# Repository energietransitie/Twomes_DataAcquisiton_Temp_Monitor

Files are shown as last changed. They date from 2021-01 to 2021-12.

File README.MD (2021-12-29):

# Twomes Boiler Monitor Module Firmware
Firmware for the Twomes Boiler Monitor Module. 

## Table of contents
* [General info](#general-info)
* [Deploying](#deploying)
* [Developing](#developing) 
* [Features](#features)
* [Pairing](#pairing)
* [Status](#status)
* [License](#license)
* [Credits](#credits)

## General info
This firmware is designed to run on the ESP32 of the [Twomes Temperature Monitor hardware](https://github.com/energietransitie/twomes-temp-monitor-hardware), in combination with two [DS18b20(Z)](https://www.maximintegrated.com/en/products/sensors/DS18B20.html) temperature sensors in clamps that can be connected the supply water piple (from the boiler to the hydronic radiators) and return water pipes returning from the hydronic radiators to the boiler. We do not expect the end user of the device to be able to distinguish between supply and return water pipes and leave the determination of supply and return to the analysis phase of the data.

The ESP32 reads the temperatures from both sensors and stores them in [RTC fast memory](https://docs.espressif.com/projects/esp-idf/en/latest/esp32/api-guides/memory-types.html#rtc-fast-memory), to preserve them during the deep sleep interval between brief moments when the ESP32 needs to be awake for data acquisition. After a series of 20 measurements at fixed time intervals, the ESP32 will send the series of measurements to the [Twomes P1 Gateway measurement device](https://github.com/energietransitie/twomes-p1-gateway-firmware) using the ESP-NOW protocol.

Via the [Twomes P1 Gateway measurement device](https://github.com/energietransitie/twomes-p1-gateway-firmware), the Twomes Boiler Monitor Module sends the following properties to the Twomes server:
| Sensor  | Property | Unit | [Printf format](https://en.wikipedia.org/wiki/Printf_format_string) | Measurement interval \[h:mm:ss\] | Description |
|---|---|---|---|---|---|
| DS18b20 | `boilerTemp1` | °C | %.1f | 0:00:10 | temperature of hydronic supply/return pipe |
| DS18b20 | `boilerTemp2` | °C | %.1f | 0:00:10 | temperature of hydronic supply/return pipe |

## Pairing
After [deploying](#deploying) and installation in the home, the Twomes Boiler Monitor Module should be [paired as a satellite to the Twomes P1 Gateway measurement device](https://github.com/energietransitie/twomes-p1-gateway-firmware/blob/main/README.md#pairing-satellites).

## Deploying
This section describes how you can deploy binary releases of the firmware, i.e. without changing the source code, without a development environment and without needing to compile the source code.

### Prerequisites
To deploy the firmware, in addition to the [generic prerequisites for deploying Twomes firmware](https://github.com/energietransitie/twomes-generic-esp-firmware#prerequisites), you need:
* a 3.3V TTL-USB Serial Port Adapter (e.g. [FT232RL](https://www.tinytronics.nl/shop/en/communication-and-signals/usb/ft232rl-3.3v-5v-ttl-usb-serial-port-adapter), CP210x, etc..), including the cable to connect ths adapter to a free USB port on your computer (a USB to miniUSB cable in the case of a [FT232RL](https://www.tinytronics.nl/shop/en/communication-and-signals/usb/ft232rl-3.3v-5v-ttl-usb-serial-port-adapter));
* You need to place a 3.6V Lithium AA-battery (e.g. SAFT LS14500) in its holder to power the board, as the Twomes Boiler Monitor Module is not powered via the 6 pin programming connector.
* Find a row of 6 holes holes (J1 in the corner of the PCB of the Boiler Monitor Module), find the `GND` pin (see  top of the PCB), align the 6 pins of the serial port adapter such that `GND` and other pins match; then connect the serial port adapter to your computer and connect the 6 pins of the serial port adapter to the 6 holes on the PCB.

### Uploading firmware
* Download the [binary release for your device](https://github.com/energietransitie/twomes-boiler-monitor-firmware/releases) and extract it to a directory of your choice.
* Follow the [generic Twomes firmware upload instructions ](https://github.com/energietransitie/twomes-generic-esp-firmware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), with the exceptions mentioned below:
	* When you see the beginning of the sequence `Connecting ......_____......`, press and hold the button labeled `GPIO0 (SW2)` on the PCB, then briefly press the button labeled `RESET (SW1)`. 
	* You should see an indication that the firmware is being written to the device.
 	* When the upload is finished, view the serial output with a serial monitor tool like [PuTTY](https://www.chiark.greenend.org.uk/~sgtatham/putty/) or the utility of your IDE (115200 baud). Press `RESET (SW1)` shortly to  make sure the firmware boots. 
	* Remove the battery or insert a battery insulating pull tab when you do not plan to use the boiler monitor module immediately, to prevent unnecessary battery drain. In particular, when the temperature sensors are not connected, power consumption is higher. 

## Developing 
This section describes how you can change the source code using a development environment and compile the source code into a binary release of the firmware that can be depoyed, either via the development environment, or via the method described in the section [Deploying](#deploying).

Please see the [generic Twomes firmware developing instructions](https://github.com/energietransitie/twomes-generic-esp-firmware#developing), with the exceptions mentioned below:
* When you see the beginning of the sequence `Connecting ......_____......`, press and hold the button labeled `GPIO0 (SW2)` on the PCB, then briefly press the button labeled `RESET (SW1)`. 
* You should see an indication that the firmware is being written to the device.

## Features
List of features ready and TODOs for future development. 

Ready:
* Pairing with a [Twomes P1 Gateway measurement device](https://github.com/energietransitie/twomes-p1-gateway-firmware)
* Measure temperatures using two DS18b20 sensors
* Deep sleep between data acquisition for ultra-low power consumption
* Send measurement data to [Twomes P1 Gateway measurement device](https://github.com/energietransitie/twomes-p1-gateway-firmware) using ESP-NOW

To-do:
* Align indication of status and error via LEDs with other measurement devices.

## Status
Project is: in Progress.

## License
This software is available under the [Apache 2.0 license](./LICENSE.md), Copyright 2021 [Research group Energy Transition, Windesheim University of Applied Sciences](https://windesheim.nl/energietransitie) 

## Credits
This software is a collaborative effort of:
* Sjors Smit ·  [@Shorts1999](https://github.com/Shorts1999)
* Fredrik-Otto Lautenbag ·  [@Fredrik1997](https://github.com/Fredrik1997)
* Gerwin Buma ·  [@GerwinBuma](https://github.com/GerwinBuma) 
* Werner Heetebrij ·  [@Werner-Heetebrij](https://github.com/Werner-Heetebrij)
* Henri ter Hofte · [@henriterhofte](https://github.com/henriterhofte) · Twitter [@HeNRGi](https://twitter.com/HeNRGi)

Product owner:
* Marco Winkelman · [@MarcoW71](https://github.com/MarcoW71)

We use and gratefully acknowlegde the efforts of the makers of the following source code and libraries:

* [Arduino core for the ESP32](https://github.com/espressif/arduino-esp32), by Espressif, licensed under [GNU LGPL-2.1](https://github.com/espressif/arduino-esp32/blob/master/LICENSE.md)
* [Library for Dallas/Maxim 1-Wire Chips](https://github.com/PaulStoffregen/OneWire), by Paul Stoffregen and others, licensed under [various licernses](https://github.com/PaulStoffregen/OneWire)
* [Arduino Library for Maxim Temperature Integrated Circuits](https://github.com/milesburton/Arduino-Temperature-Control-Library), by Miles Burton, licensed under [GNU LGPL-2.1](https://github.com/milesburton/Arduino-Temperature-Control-Library#license)

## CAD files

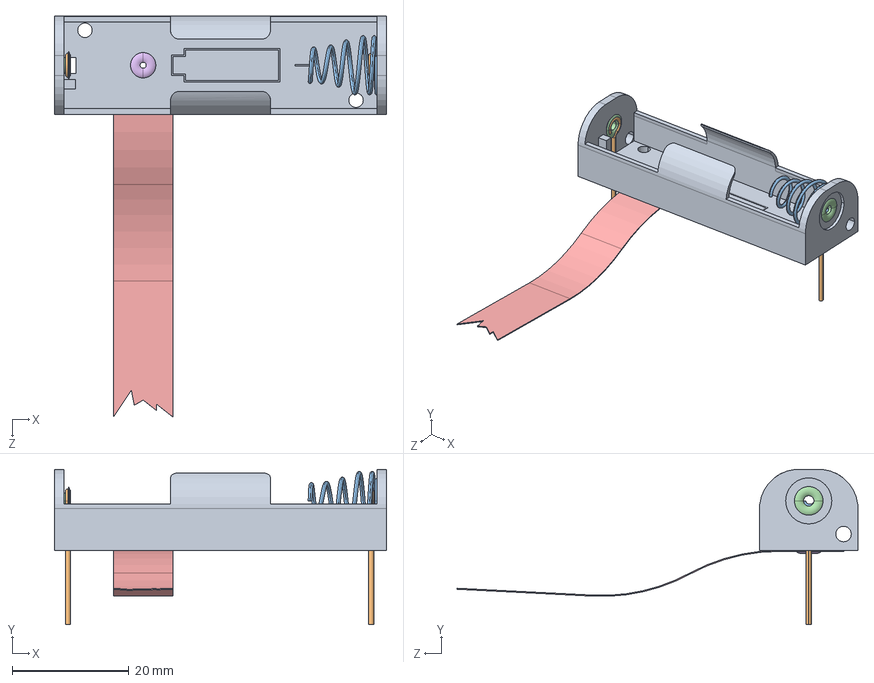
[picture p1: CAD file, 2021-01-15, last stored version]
hardware_design/models/keystone-PN2460RB.SLDASM
57.0 x 26.6 x 68.8 mm
2460-1RB.STEP
2464-2.STEP x 2
2464-spring1.STEP
2460-2_for assemly.STEP x 2
Ribon-Red.STEP
2464-for ribon.STEP

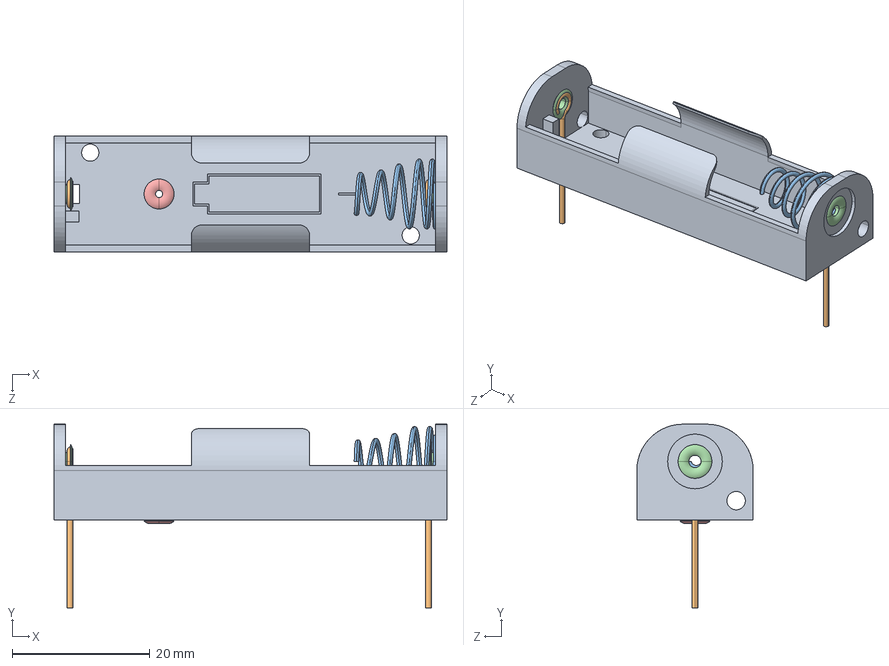
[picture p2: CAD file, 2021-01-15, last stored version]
hardware_design/models/keystone-PN2460_without_ribbon.STEP
57.0 x 26.6 x 16.9 mm
2460-1RB.STEP
2464-2.STEP x 2
2464-spring1.STEP
2460-2_for assemly.STEP x 2
2464-for ribon.STEP

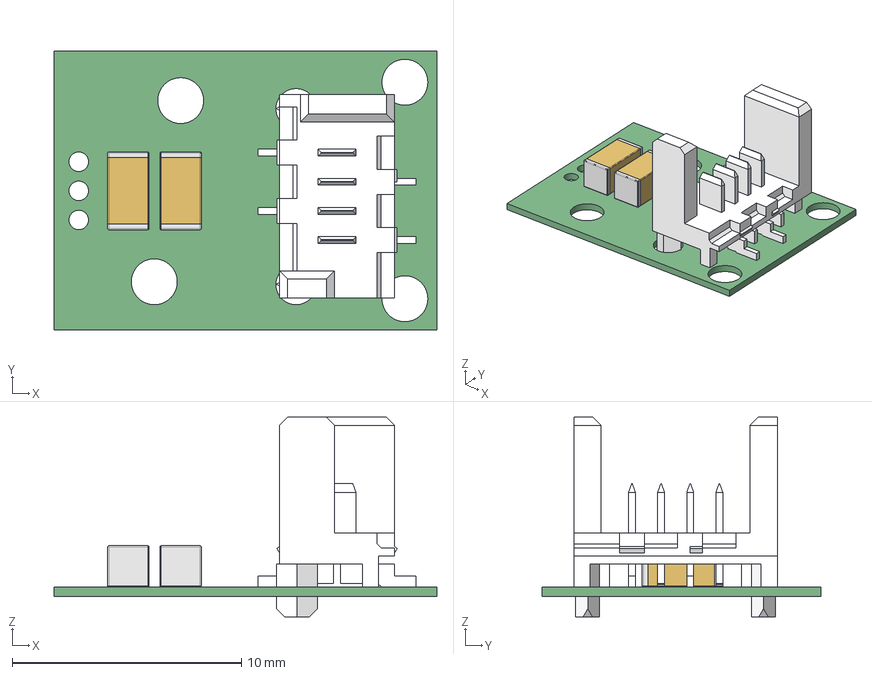
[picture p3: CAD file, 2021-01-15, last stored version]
hardware_design/Twomes_Monitor_slave.step
16.7 x 12.2 x 8.70 mm

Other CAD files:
hardware_design/Open_CASCADE_STEP_translator_6.8_1.3.1.x_t.SLDPRT
hardware_design/models/keystone-PN2460_without_ribbon.SLDASM

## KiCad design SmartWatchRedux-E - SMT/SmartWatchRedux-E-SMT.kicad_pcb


Board: 2 copper layers, 24.7 x 69.9 mm, 6 parts (0 on the bottom side), 33 nets.

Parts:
BAT1: CR2032; BatteryHolder_Keystone_1060_1x2032
C1: 0.1uF; C_1206_3216Metric
CN1: 27C256Socket; DIP-28_W15.24mm
U1: ROM; DIP-28_W15.24mm_Socket
U2: DS1315; DIP-16_W7.62mm
Y1: 32.768 KHz; Crystal_SMD_3215-2Pin_3.2x1.5mm

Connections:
/XTAL1: U2.1, Y1.1
/XTAL2: U2.2, Y1.2
GND: BAT1.2, C1.2, CN1.14, U1.14, U2.5, U2.8, U2.14
unnamed: BAT1.1, U2.4
unnamed: CN1.1, U1.1, U2.13
unnamed: CN1.2, U1.2
unnamed: CN1.3, U1.3
unnamed: CN1.4, U1.4
unnamed: CN1.5, U1.5
unnamed: CN1.6, U1.6
unnamed: CN1.7, U1.7
unnamed: CN1.8, U1.8, U2.3
unnamed: CN1.9, U1.9
unnamed: CN1.10, U1.10, U2.6
unnamed: CN1.11, U1.11, U2.7
unnamed: CN1.12, U1.12
unnamed: CN1.13, U1.13
unnamed: CN1.15, U1.15
unnamed: CN1.16, U1.16
unnamed: CN1.17, U1.17
unnamed: CN1.18, U1.18
unnamed: CN1.19, U1.19
unnamed: CN1.20, U2.11
unnamed: CN1.21, U1.21
unnamed: CN1.22, U1.22, U2.12
unnamed: CN1.23, U1.23
unnamed: CN1.24, U1.24
unnamed: CN1.25, U1.25
unnamed: CN1.26, U1.26
unnamed: CN1.27, U1.27
unnamed: U1.20, U2.10
unnamed: U2.9, U2.15
VCC: C1.1, CN1.28, U1.28, U2.16

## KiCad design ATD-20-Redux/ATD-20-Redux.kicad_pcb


Board: 2 copper layers, 24.3 x 64.1 mm, 5 parts (0 on the bottom side), 9 nets.

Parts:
BAT1: CR2032; BatteryHolder_Keystone_1060_1x2032
C1: 0.1uF; C_Disc_D4.3mm_W1.9mm_P5.00mm
J1: RTC Pins; DIP-28_W15.24mm_Socket
U1: DS1315; DIP-16_W7.62mm
Y1: 32.768 KHz; Crystal_C38-LF_D3.0mm_L8.0mm_Horizontal

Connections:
/D0: J1.11, U1.6, U1.7
/XTAL1: U1.1, Y1.1
/XTAL2: U1.2, Y1.2
/~CS_RTC: J1.20, U1.11
/~IOR: J1.22, U1.12
/~IOW: J1.27, U1.3
GND: BAT1.2, C1.2, J1.14, U1.5, U1.8, U1.9, U1.14
unnamed: BAT1.1, U1.4
VCC: C1.1, J1.28, U1.13, U1.16

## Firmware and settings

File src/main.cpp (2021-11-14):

#include <Arduino.h>
#include <OneWire.h>           //for DS18B20 support
#include <DallasTemperature.h> //for DS18B20 support
#include <WiFi.h>               //For setting WiFi mode REVIEW could this be done using the esp_wifi.h as well?
#include <esp_now.h>            //For sending and receiving ESP-NOW messages
#include <espnow_settings.h>    //Contains addresses and message limits
#include <esp_wifi.h>           //For setting channel
#include <nvs.h>                //For storing and reading Gateway MAC and channel
#include <rom/rtc.h>            //Get wakeup reason

//Roomsensor libraries are made in C:
//Should the extern "C" be moved to inside the libraries?
#ifdef __cplusplus
extern "C" {
#endif
#include <sensor_IO.h>
#include <twomes_sensor_pairing.h>
#ifdef __cplusplus
}
#endif

//DEBUG DEFINES:
#define DEBUG 1              //Global debug define enable

#define DEBUG_BOOT 1            //Debug startup (Able to boot, check for temp-sensors, CPU frequency)
#define DEBUG_TEMPERATURE 1     //Debug Temperature measurements (Print temperature values)
#define DEBUG_TIME 1            //Debug the time adjustment value (Print time since last boot in us)
#define DEBUG_ESPNOW_SEND 1     //Debug for when sending ESP-Now messages (Print payload and destination MAC address)
#define DEBUG_CALLBACK 1        //Debug for ESP-Now callback function (de-initalising and check for ACK)
#define DEBUG_ERRORS 1          //Debug error-messages (init-failures)
#define DEBUG_PROVISIONING 1    //Debug sensor provisioning

/** -------------------------------------------------/
 * @todo:
 * - Test sensor readings [V]
 * - set configurable settings using GPIO or Provisioning through Gateway []
 * - Change temp reading in float to temp reading in uint16_t [V]
 * - Put Debug/Serial operation in #if to disable for real tests [V]
 * - Improve code readability []
 * - implement support for roomTemp version (si7051 sensor) [] //REVIEW should this be entirely seperate code?
 * - automate deep- or light sleep depending on interval time [] (light sleep for <=10 seconds, deep sleep for >10 seconds)
----------------------------------------------------*/

#define ONEWIRE_BUS_PIN 25  //pin for OneWire bus
#define SUPERCAP_ENABLE 27  //Pull low to enable supercap

#define uS_TO_S_FACTOR 1000000ULL                    /* Conversion factor for micro seconds to seconds */
#define mS_TO_S_FACTOR 1000ULL                       /* Conversion factor for milli seconds to seconds */
#define TIME_TO_SLEEP 10                             /* Time between measurements */
#define INTERVAL_US (TIME_TO_SLEEP * uS_TO_S_FACTOR) /* desired interval between measurements in us */
#define TIME_TO_CONVERSION 750                       /* Time ESP32 will go to sleep for conversion(in milliseconds) */
#define RETRY_INTERVAL 5                             /* Amount of measurements before a new ESP-Now attempt after a Fail To Send */

#define PAIRING_TIMEOUT_uS 20*uS_TO_S_FACTOR         /* timeout for pairing mode*/

#define MAX_SAMPLES_MEMORY 60    //maximum memory allocated for samples, derived from maximum amount of samples that fit into a single message
#define ESPNOW_SEND_MINIMUM 20       //Minimum amount of measurements taken before ESP-Now transmissions are started

#if (MAX_SAMPLES_MEMORY != MAX_SAMPLES_ESPNOW)
#error This is not supported yet
#endif

//systemStates
enum systemStates {
    UNKNOWN,           //boot after power loss (RTC data cleared) or first boot
    INIT_MEASUREMENT,  //state where measurement is initialised
    READ_MEASUREMENT,   //state where measurement is read
    PROVISION_SENSOR    //State where sensor gets provisioned with channel and gateway MAC through ESP-Now
}; /* systemstates*/
RTC_DATA_ATTR systemStates systemState = UNKNOWN;           //variable in RTC memory where current system state is saved

RTC_DATA_ATTR uint8_t currentMeasurement = 0;       //variable in RTC memory where number of current measurement is stored
RTC_DATA_ATTR uint64_t previousTime = 0;            //REVIEW
RTC_DATA_ATTR uint64_t time_correction = 200000;    //REVIEW, initial time correction
RTC_DATA_ATTR uint16_t burstNumber = 0;             //Store the amount of databursts that have been done with ESP-Now, for syncing with gateway

//Register peer
esp_now_peer_info_t peerInfo; //place to save ESPNOW peer info

//prototype functions
void sendESPNOWmessage(); //function to send ESPNOW message
void onDataSent(const uint8_t *macAddress, esp_now_send_status_t status); //ESP-Now send callback function
void onDataReceive(const uint8_t *macAddress, const uint8_t *payload, int length); //ESP-Now receive callabck function

OneWire oneWireBus(ONEWIRE_BUS_PIN); //software OneWire bus

DallasTemperature tempSensors(&oneWireBus); //temperature object


RTC_DATA_ATTR int16_t temp1[MAX_SAMPLES_MEMORY];
RTC_DATA_ATTR int16_t temp2[MAX_SAMPLES_MEMORY];
RTC_DATA_ATTR bool waitForCallback = false;

//Twomes Measurement type enum:
enum ESPNOWdataTypes {
    BOILERTEMP,
    ROOMTEMP,
    CO2,
};

//NEW int16_t version to increase amount of measurements in single burst
typedef struct ESP_message {
    uint8_t measurementType = BOILERTEMP;  //Type of measurements
    uint8_t numberofMeasurements;                       //number of measurements in burst
    uint16_t index;                                     //Number identifying the message, only increments on receiving an ACK from Gateway. Could be uint8_t since overflows are ignored?
    uint16_t intervalTime = TIME_TO_SLEEP;               //Interval between measurements, for timestamping in gateway
    int16_t pipeTemps1[MAX_SAMPLES_ESPNOW];             //measurements of the first temperature sensor
    int16_t pipeTemps2[MAX_SAMPLES_ESPNOW];             //measurements of the second temperature sensor
} ESP_message;
ESP_message prepareMessage; //allocate space for this struct //Should/can this be done dynamically?

void setup() {
#if defined(DEBUG) //Serial only has to be started when debugging:
    Serial.begin(115200);
#endif
    pinMode(BUTTON_GPIO0_SW2, INPUT_PULLUP);
    pinMode(BUTTON_GPIO15_SW3, INPUT_PULLUP);
    pinMode(GREEN_LED_STATUS_D2, OUTPUT);
    pinMode(RED_LED_ERROR_D1, OUTPUT);
    pinMode(SUPERCAP_ENABLE, OUTPUT);
    digitalWrite(SUPERCAP_ENABLE, HIGH); //Pmos = active low

    //Get the wakeup reason:
    RESET_REASON reset_reason = rtc_get_reset_reason(PRO_CPU_NUM);
    if (reset_reason == RTCWDT_BROWN_OUT_RESET) {
        delay(10000);
        reset_reason = POWERON_RESET;
    }
    //Check for BUTTON_GPIO15_SW3 pressed on boot
    if (reset_reason == POWERON_RESET) {
        systemState = systemStates::PROVISION_SENSOR;
    } //if(!digitalRead(BUTTON_GPIO15_SW3))

    //Needs loop for lightsleep, since program counter is saved
    while (1) {
        //this is a state machine
        switch (systemState) {
            //First boot or power loss, re-initialise:
            case systemStates::UNKNOWN: //first run/sensors not connected?, this could be detection for hardware variant
#if defined(DEBUG) & defined(DEBUG_BOOT)
//Blink LED to indicate being in state "UNKNOWN"
                digitalWrite(RED_LED_ERROR_D1, HIGH);
                delay(50);
                digitalWrite(RED_LED_ERROR_D1, LOW);
                delay(50);
                digitalWrite(RED_LED_ERROR_D1, HIGH);
                delay(50);
                digitalWrite(RED_LED_ERROR_D1, LOW);
                Serial.println("Device has started");
                Serial.println("booted for the first time");
#endif
                tempSensors.begin();
                delay(50); //give time for initing
                //Check that both sensors are connected:
                if (tempSensors.getDeviceCount() != 2) {
#if defined(DEBUG) & defined(DEBUG_BOOT)
                    Serial.println("Missing temperature sensors!");
                    Serial.println(tempSensors.getDeviceCount());
#endif
                    delay(500);
                } //if getDeviceCount != 2
                else {
#if defined(DEBUG) & defined(DEBUG_BOOT)
                    Serial.println("Ready to start measuring!");
#endif
                    systemState = systemStates::INIT_MEASUREMENT;
                } //if get DeviceCount == 2
                break; //systemStates::UNKNOWN
            //init measurement
            case systemStates::INIT_MEASUREMENT:
                tempSensors.begin();                     //initialize sensor
                tempSensors.setWaitForConversion(false); //disable the wait for conversion
                tempSensors.requestTemperatures();       //start conversion
                esp_sleep_enable_timer_wakeup(TIME_TO_CONVERSION * mS_TO_S_FACTOR); //sleep for 750 ms during conversion

                systemState = systemStates::READ_MEASUREMENT; //set conversion is started bit

                esp_light_sleep_start(); //go to sleep

                break; //end of systemStates::INIT_MEASUREMENT
            case systemStates::READ_MEASUREMENT: //read measurements
            {
#if defined(DEBUG) & defined(DEBUG_BOOT)
                Serial.println("Device has started");
#endif
                //Theoretically speaking, currentMeasurement should in this case always be equal to MAX_SAMPLES_MEMORY, and never exceed it.
                if (currentMeasurement >= MAX_SAMPLES_MEMORY) {
                    //move all samples "RETRY_INTERVAL" amount of spaces in memory, overwriting "RETRY_INTERVAL" amount of old measurements and making room for "RETRY_INTERVAL" amount new ones.
                    memmove(temp1, &temp1[(currentMeasurement - MAX_SAMPLES_MEMORY) + RETRY_INTERVAL], (MAX_SAMPLES_MEMORY - RETRY_INTERVAL) * sizeof(temp1[0]));
                    memmove(temp2, &temp2[(currentMeasurement - MAX_SAMPLES_MEMORY) + RETRY_INTERVAL], (MAX_SAMPLES_MEMORY - RETRY_INTERVAL) * sizeof(temp2[0]));
                    currentMeasurement = MAX_SAMPLES_MEMORY - RETRY_INTERVAL;
                }//if(currentMeasurement >= MAX_SAMPLES_MEMORY)

                DeviceAddress address1;
                DeviceAddress address2;
                tempSensors.getAddress(address1, 0);
                tempSensors.getAddress(address2, 1); //Using same bus
                temp1[currentMeasurement] = tempSensors.getTemp(address1);
                temp2[currentMeasurement] = tempSensors.getTemp(address2); //Using same bus
#if defined(DEBUG) & defined(DEBUG_TEMPERATURE)
                Serial.print("Temp1: ");
                Serial.println(temp1[currentMeasurement], HEX);
                Serial.print("Temp2: ");
                Serial.println(temp2[currentMeasurement], HEX);
                Serial.print("Celsius values: ");
                Serial.print("Temp 1: ");
                Serial.print(temp1[currentMeasurement] * 0.0078125f); //Conversion to Celsius from DallasTemperature library to check if HEX value was read correctly
                Serial.print("Temp 2: ");
                Serial.println(temp2[currentMeasurement] * 0.0078125f); //Conversion to Celsius from DallasTemperature library to check if HEX value was read correctly
#endif
                if ((temp1[currentMeasurement] == DEVICE_DISCONNECTED_RAW) || (temp2[currentMeasurement] == DEVICE_DISCONNECTED_RAW)) {
#if defined(DEBUG) & defined(DEBUG_TEMPERATURE)
                    Serial.println("\n\n\n\nNow everything should be deleted, and starting again"); //temp error message
#endif
                    currentMeasurement = 0;            //set to zero to reinit all.
                    systemState = systemStates::UNKNOWN; //go back to previous step
                    break;                             // init everything again
                }//if(temp1 || temp2)
                currentMeasurement++; //Add to currentMeasurement AFTER measuring, but BEFORE sending! (0 indexing for writing to memory, but not for comparing to ready_to_send)
#if defined(DEBUG) & defined(DEBUG_TEMPERATURE)
                Serial.printf("\n\n\ncurrentMeasurement: %u\n", currentMeasurement);
#endif
                struct timeval tv;
                gettimeofday(&tv, NULL);
                int64_t time_us = (int64_t)tv.tv_sec * 1000000L + (int64_t)tv.tv_usec; //code needed to get the time in microseconds
                int32_t time_delta = time_us - previousTime;                          //calculate the time that is elapsed since the last measurement
                previousTime = time_us;                                               // write current time to memory for next cycle
#if defined(DEBUG) & defined(DEBUG_TIME)
                Serial.println(time_delta);
#endif
                time_correction += (time_delta - INTERVAL_US);                                   // finetune time correction
                esp_sleep_enable_timer_wakeup(TIME_TO_SLEEP * uS_TO_S_FACTOR - time_correction); //sleep until next temperature reading
                //if there are not enough samples yet
                if (currentMeasurement < ESPNOW_SEND_MINIMUM) {
#if defined(DEBUG) & defined(DEBUG_TEMPERATURE)
                    Serial.printf("Collecting new measurement\n");
#endif
                } //if(currentMEasurement<ESPNOW_SEND_MINIMUM)
                else if (currentMeasurement == ESPNOW_SEND_MINIMUM || (currentMeasurement > ESPNOW_SEND_MINIMUM && !((currentMeasurement - ESPNOW_SEND_MINIMUM) % RETRY_INTERVAL))) { //if there are enough samples to send
                    sendESPNOWmessage();
                    waitForCallback = true;
                    while (waitForCallback) {
#if defined(DEBUG) && defined(DEBUG_CALLBACK)
                        Serial.println("waiting for callback");
#endif
                        delay(500);
                    } //Wait for ESP-Now Callback function
                }//esle if (enough samples to send)

                systemState = systemStates::INIT_MEASUREMENT;
#ifdef DEBUG
                Serial.println("Entering Sleep mode");
#endif
#if (TIME_TO_SLEEP>5)  //at a delay of more than 10 
                esp_deep_sleep_start();
#else
                esp_light_sleep_start(); //go to sleep
#endif
            }//case READ_MEASUREMENT
            break;

            case systemStates::PROVISION_SENSOR:
            {
                Serial.println("In pairing mode");
                digitalWrite(SUPERCAP_ENABLE, LOW); //Enable supercap
                WiFi.mode(WIFI_STA); //Enter STA mode to enable ESP-Now
                if (esp_now_init() != ESP_OK) { //if initing wasn't succesful
#if defined(DEBUG) & defined(DEBUG_ERRORS)
                    Serial.println("Error initializing ESP-NOW");
#endif
                    esp_now_deinit();
                    WiFi.mode(WIFI_OFF);
                    break;
                }
                //Set the channel to the defined channel for Sensor pairing (Should be the same in the P1-Gateway!!)
                esp_wifi_set_channel(ESPNOW_PAIRING_CHANNEL, WIFI_SECOND_CHAN_NONE);

                esp_now_register_recv_cb(onDataReceive);
                int64_t startTime = esp_timer_get_time();
                //Set 20 second timeout on pairing:
                while ((startTime + PAIRING_TIMEOUT_uS > esp_timer_get_time())) {
                    digitalWrite(GREEN_LED_STATUS_D2, HIGH);
                    vTaskDelay(500);
                    digitalWrite(GREEN_LED_STATUS_D2, LOW);
                    vTaskDelay(500);
                }
                esp_now_unregister_recv_cb();
                esp_now_deinit();
                WiFi.mode(WIFI_OFF);
                digitalWrite(SUPERCAP_ENABLE, HIGH); //Close supercap
                //Indicate pair fail:
                gpio_set_level((gpio_num_t)RED_LED_ERROR_D1, 1);
                delay(5000);
                systemState = systemStates::UNKNOWN;
            }//case PROVISION_SENSOR
            break;
            default:
            {
            }//default
            break;
        }// switch systemState
    } //while(1)
}

void sendESPNOWmessage() {
    //Enable SuperCap to assist with power:
    digitalWrite(SUPERCAP_ENABLE, LOW);

    //Get the MAC address and channel from NVS:
    uint8_t macAddress[6];
    uint8_t channel;
    esp_err_t err = getGatewayData(macAddress, sizeof(macAddress), &channel);
    if (err != ESP_OK) {
        ESP_LOGE("READ-CHANNEL", "Error trying to read data from NVS: %s", esp_err_to_name(err));
    }

    //Enable Wi-Fi in station mode, to allow ESP-Now
    WiFi.mode(WIFI_STA);

    if (esp_now_init() != ESP_OK) { //if initing wasn't succesful, exit
#if defined(DEBUG) & defined(DEBUG_ERRORS)
        Serial.println("Error initializing ESP-NOW");
#endif
        esp_now_deinit();
        WiFi.mode(WIFI_OFF);
        return;
    }

    esp_now_register_send_cb(onDataSent); //register callback to fetch send reaction

#if defined(DEBUG)
//print the read channel and MAC address
    Serial.print(" Now validating NVS address: ");
    for (uint8_t i = 0; i < 6;i++) {
        Serial.print(macAddress[i], HEX);
        Serial.print(':');
    }
    Serial.printf("Sending on channel %u", channel);
#endif
    // Add peer
    memcpy(peerInfo.peer_addr, macAddress, 6);
    //Before sending, retrieve the Wi-Fi channel of the local network:
    esp_wifi_set_channel(channel, WIFI_SECOND_CHAN_NONE);

    if (esp_now_add_peer(&peerInfo) != ESP_OK) //add to peer
    {
#if defined(DEBUG) & defined(DEBUG_ERRORS)
        Serial.println("Failed to add peer");
#endif
        esp_now_deinit();
        WiFi.mode(WIFI_OFF);
        //esp_now_del_peer(&peerInfo.peer_addr);
        return;
    }


    prepareMessage.numberofMeasurements = currentMeasurement;
    prepareMessage.index = burstNumber;
    //Copy the temperature data into the struct
    memcpy(prepareMessage.pipeTemps1, temp1, MAX_SAMPLES_MEMORY * sizeof(temp1[0]));
    memcpy(prepareMessage.pipeTemps2, temp2, MAX_SAMPLES_MEMORY * sizeof(temp2[0]));
#if defined(DEBUG_ESPNOW_SEND) & defined(DEBUG)
    // Serial.printf("[ESPNOW]: prepareMessage.numberofMeasurements = %u\n", prepareMessage.numberofMeasurements);
    // Serial.printf("[ESPNOW]: prepareMessage.intervalTime = %u\n", prepareMessage.intervalTime);
    // Serial.printf("[ESPNOW]: preparemessage.index = %u\n", prepareMessage.index);
    // for (uint8_t counter1 = 0; counter1 < prepareMessage.numberofMeasurements; counter1++) {
    //     // printf("[ESPNOW]: prepareMessage.pipeTemps1[%u] = %f\n", counter1, prepareMessage.pipeTemps1[counter1]); //Old float version
    //     // printf("[ESPNOW]: prepareMessage.pipeTemps2[%u] = %f\n", counter1, prepareMessage.pipeTemps2[counter1]);
    //     Serial.printf("[ESPNOW]: prepareMessage.pipeTemps1[%u] = %f\n", counter1, prepareMessage.pipeTemps1[counter1] * 0.0078125f); //New int16_t, print as float for debugging
    //     Serial.printf("[ESPNOW]: prepareMessage.pipeTemps2[%u] = %f\n", counter1, prepareMessage.pipeTemps2[counter1] * 0.0078125f);
    // }
    // Serial.printf("[ESPNOW]: This should be the message\n");
#endif

    //Send the data through ESP-Now
    esp_err_t result = esp_now_send(macAddress, (uint8_t *)&prepareMessage, sizeof(prepareMessage));

    //Check that the message was correctly transmitted 
    if (result != ESP_OK) {
#if defined(DEBUG) & defined(DEBUG_ESPNOW_SEND)
        Serial.printf("Error sending the data, with return %u\n", result);
#endif
        esp_now_deinit();
        WiFi.mode(WIFI_OFF);
        return;
    }
#if defined(DEBUG) & defined(DEBUG_ESPNOW_SEND)
    else {
        Serial.print("[ESPNOW]: Sent with success to address: ");
        for (uint8_t i = 0; i < 6; i++) {
            Serial.print((peerInfo.peer_addr[i]), HEX);
            Serial.print(":");
        }
        Serial.println();
    }
#else
    else
        return;
#endif
}

//callback on ESP message sent, use status to check for ACK
void onDataSent(const uint8_t *macAddress, esp_now_send_status_t status) {
#if defined(DEBUG) & defined(DEBUG_CALLBACK)
    Serial.printf("[ESPNOW]: unregister cb: %d\n", esp_now_unregister_send_cb());
    // Serial.printf("[ESPNOW]: delete peer: %d\n", esp_now_del_peer(gatewayAddress));
    Serial.println(String("[ESP-Now] De-init ") + String((esp_now_deinit() ? "failed" : "Succes")));
    Serial.println(String("[WiFi] Turn off WiFi ") + String(WiFi.mode(WIFI_OFF) ? "Succes" : "Failed"));
#else
    esp_now_unregister_send_cb();
    esp_now_del_peer(gatewayAddress);
    esp_now_deinit();
    WiFi.mode(WIFI_OFF);
#endif
    digitalWrite(SUPERCAP_ENABLE, HIGH); //Disable supercap
#if defined(DEBUG) & defined(DEBUG_CALLBACK)
    Serial.print("\r\nLast Packet Send Status: ");
#endif
    if (status == ESP_NOW_SEND_SUCCESS) {
#if defined(DEBUG) & defined(DEBUG_CALLBACK)
        Serial.printf("Delivery Success, so currentMeasurement =0\n");
#endif
        currentMeasurement = 0; //zero this if measurement succeed
        burstNumber++;          //Add to the total amount of samples sent
    }
#if defined(DEBUG) & defined(DEBUG_CALLBACK)
    else {
        Serial.printf("Delivery Fail\n");
    }
#endif
    //Go to sleep only after ESP_Now message is completely processed

    waitForCallback = false;
    return;
}



void loop() {}

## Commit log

2020-11-11 change foldername due false characters
    [Twomes_Monitor.PrjPCB, main.SchDoc]
2020-12-02 working on schematic
    [Twomes_Monitor.PrjPCB, Twomes_Monitor.SCHLIB, main.SchDoc]
2020-12-03 hardware developing
    [Twomes_Monitor.SCHLIB, Twomes_Monitor_master.PrjPCB, Twomes_Monitor_master.xls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]
2020-12-03 80 percent developed
    [main_master.SchDoc]
2020-12-04 almost finished
    [Twomes_Monitor_master.PrjPCB, main_master.SchDoc, tempSensor_master.SchDoc]
2020-12-04 deleted renamed files
    [Twomes_Monitor.PrjPCB, Twomes_Monitor.SCHLIB, main.SchDoc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]
2020-12-06 this version will be first prototype
    [Open_CASCADE_STEP_translator_6.8_1.3.1.x_t.SLDPRT, Twomes_Monitor_master.PrjPCB, main_master.SchDoc]
2021-01-06 this version is prototype 1
    [Twomes_Monitor_master.PrjPCB, Twomes_Monitor_slave.PcbDoc, Twomes_Monitor_slave.PrjPCB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]
2021-01-15 current hard en software to master
2021-01-19 prepared hardware designs for presentations and handover
    [main_master.SchDoc]
2021-01-19 manually merged from tempSens_low-power, introduced sytemState machine, support two DS18B20, designed state machine with merged sleep functions, prepared espnow send functions for multiple measuremen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
2021-01-21 developed system for reuse RTC measurements memory, configured compiler error for memory allocation, made sensor 2 operational
    [main.cpp]
2021-04-13 New Open Source Hardware using KiCad
    [TwomesSensor.kicad_pcb, TwomesSensor.sch]
2021-05-20 New devicetype identifiers
2021-06-10 Add support for sensor pairing
2021-06-22 Remove old hardware
    Old hardware files still exist in "Legacy" branch
    [Open_CASCADE_STEP_translator_6.8_1.3.1.x_t.SLDPRT, Twomes_Monitor_master.PrjPCB, Twomes_Monitor_master.xls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]
2021-10-10 Bootloader and general power optimizations
2021-10-27 Use new script for uploading low power bootloader
    [default_8MB.csv]
2021-10-28 Hardware has been moved to seperate repo
    See http://github.com/energietransitie/twomes-temp-monitor-hardware
    [TwomesSensor.kicad_pcb, TwomesSensor.sch]
2021-11-05 Update filenames
    [Twomes_Partitions.csv]
2021-11-05 Delay to allow supercap to charge up
2021-11-05 Clarify pairing succes/fail to enduser
    [main.cpp]
2021-11-05 Fix LED not always working
    [main.cpp]
2021-11-06 button constants follow silkscreen
2021-11-06 fix to align better with main branch
    [default_8MB.csv]
